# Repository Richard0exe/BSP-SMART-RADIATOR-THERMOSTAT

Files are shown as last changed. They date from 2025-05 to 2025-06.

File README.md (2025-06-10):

# Smart Radiator Thermostat

## Description
This project implements a smart radiator temperature control system. The system allows manual temperature adjustment via a rotary encoder, as well as remote control through a web interface. It uses ESP32 and ESP32-C3 modules, a 28BYJ-48 5V stepper motor for precise temperature regulation, an OLED display (SSD1306), and a DHT11 sensor for measuring ambient temperature. A press button is used to switch between different radiators in the system.

## Features

Manual Temperature Control: Rotate the rotary encoder to adjust the temperature setting.
Web Interface: Use the web server to control radiator temperature remotely via a browser.
Radiator Selection: Press the button to toggle between different radiators.
Real-Time Temperature Monitoring: Displays current temperature readings from the DHT11 sensor on the OLED display.
Precise Valve Control: Uses a stepper motor to adjust radiator valves according to the set temperature.
LIVE thermostat updates when sending new requests, showing status via display.

## Architecture
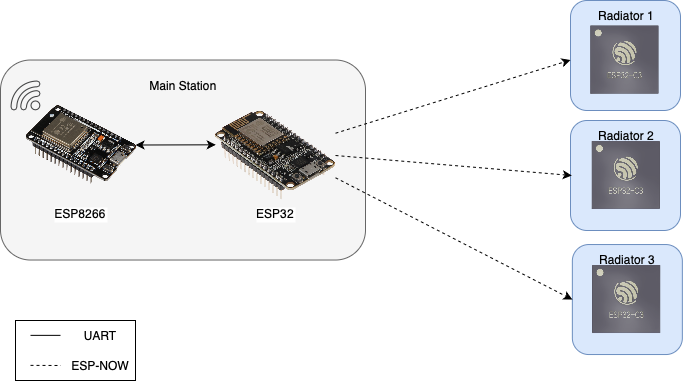
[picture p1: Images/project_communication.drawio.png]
Communication diagram


ESP32 and ESP8266 communicate using UART (Serial bus). ESP8266 holds Web server, ESP32 gets data from Web and sends using ESP-NOW to ESP32C3 radiator nodes.

## Setup

### Hardware
 - Connect the Stepper Motor (28BYJ-48) to the ESP32 using the appropriate motor driver (e.g., ULN2003).
 - OLED Display (SSD1306) connects via I2C to the ESP32.
 - Rotary Encoder connects to two GPIO pins for reading rotational data.
 - DHT11 Sensor connects to a GPIO pin for temperature sensing.
 - Press Button connects to a GPIO pin for switching between radiators.
### Software
 - Install the ESP32 Board support in the Arduino IDE.
 - Install the following libraries:
1. Adafruit_SSD1306 for the OLED display.
2. DHT for the DHT11 sensor.
3. ESPAsyncWebServer for the web server.
4. AsyncTCP
5. LittleFS
 - To Upload the code to your ESP32 use the Arduino IDE.

⚠️ **DON'T FORGET TO!** ⚠️
For uploading WEB files use LittleFS:

ARDUINO IDE -> (CMD + SHIFT + P) -> UPLOAD LittleFS to...

---

## Wiring
### Main module

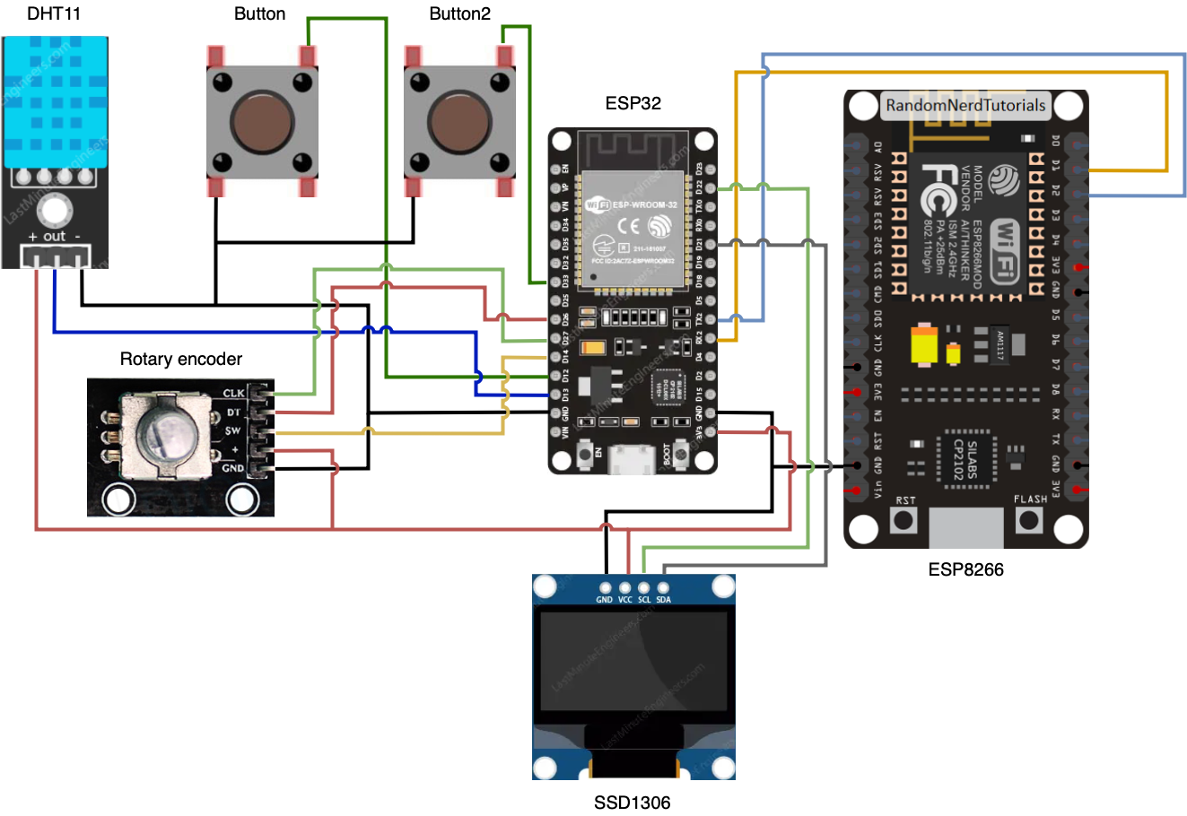
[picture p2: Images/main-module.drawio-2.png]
Main diagram


### Radiator module

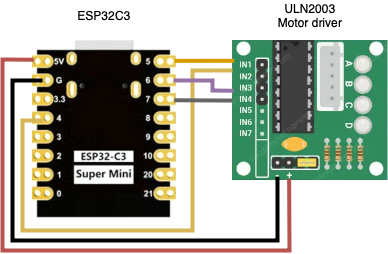
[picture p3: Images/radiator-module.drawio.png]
Radiator diagram


---

#### Web Interface
Once the system is up and running, connect your device to the same network as the ESP8266. Access the web interface by entering the ESP8266's IP address in a web browser. Use the interface to adjust the radiator temperatures remotely.
The IP address to access the server is being printed to serial port.

⚠️ **IMPORTANT!** ⚠️
To find the IP address and other information press the info button

#### Manual Control
Rotate the rotary encoder to adjust the desired temperature for the selected radiator. The OLED display will show the current temperature and the selected radiator. Use the button to switch between different radiators.

# Contributors
- [Ričards Bubišs](https://github.com/Richard0exe?tab=followers)
- [Markuss Birznieks](https://github.com/Markuss-B)

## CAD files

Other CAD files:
3D-Model/valve-trv v20.f3z

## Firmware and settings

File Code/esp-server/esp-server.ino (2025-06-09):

#include <Wire.h>
#include <Adafruit_GFX.h>
#include <Adafruit_SSD1306.h>
#include <DHT.h>
#include <DHT_U.h>
#include <ArduinoJson.h>
#include "Communications.h" 
#include "Messages.h"
#include "RadiatorManager.h"
#include "RadiatorDisplay.h"
#include "WebComs.h"
#include "Button.h"

#define DEBUG FALSE // CHANGE TO TRUE TO ENABLE SERIAL OUTPUTS 

#define SCREEN_WIDTH 128 // OLED display width, in pixels
#define SCREEN_HEIGHT 32 // OLED display height, in pixels

#define DHT_PIN 13 // D13
#define DHT_TYPE DHT11 
#define BUTTON_PIN 12 // D12
#define INFO_BUTTON_PIN 25 // D25

#define RX2 16
#define TX2 17

#define SDA_PIN 21  // Define SDA pin (GPIO 21)
#define SCL_PIN 22  // Define SCL pin (GPIO 22)

#define ENCODER_CLK 27  // D5
#define ENCODER_DT  26  // D6
#define ENCODER_SW  14  // D0 (reuses your button)

// Declaration for an SSD1306 display connected to I2C (SDA, SCL pins)
Adafruit_SSD1306 display(SCREEN_WIDTH, SCREEN_HEIGHT, &Wire, -1);
DHT dht(DHT_PIN, DHT_TYPE);

Communications coms;
RadiatorManager radiatorManager(coms);
RadiatorDisplay radiatorDisplay(display);
WebComs webComs(Serial2, radiatorManager);

Button infoButton(INFO_BUTTON_PIN);

void OnDataRecv(const uint8_t* mac, uint8_t type, const uint8_t* data, int len){
  switch (type) {
    case MSG_TYPE_TEMPERATURE_RESPONSE:
      if (len == sizeof(TemperatureResponse)) {
        TemperatureResponse payload;
        memcpy(&payload, data, sizeof(payload));
        radiatorManager.processTemperatureResponse(mac, payload);
      }
      break;

    default:
      Serial.println("Unknown message type");
      break;
  }
}

void OnDiscoverNewPeer(const Peer& peer) {
  // Add new radiator
  if (strncmp(peer.name, "radiator", MAX_NAME_LEN) == 0) {
    radiatorManager.handleDiscovery(peer);
  } else {
    Serial.printf("Discovered unknown type device: %s (%s)\n", peer.name, Communications::macToString(peer.mac).c_str());
  }
}

void setup() {
  Serial.begin(115200);
  Serial2.begin(9600, SERIAL_8N1, RX2, TX2);

  Wire.begin(SDA_PIN, SCL_PIN);

  pinMode(ENCODER_CLK, INPUT);
  pinMode(ENCODER_DT, INPUT);
  pinMode(ENCODER_SW, INPUT_PULLUP);
  
  pinMode(BUTTON_PIN, INPUT_PULLUP);
  infoButton.begin();
  // Initialize the DHT sensor
  dht.begin();
  
  // Initialize the OLED display
  if (!display.begin(SSD1306_SWITCHCAPVCC, 0x3C)) {
    Serial.println(F("SSD1306 allocation failed"));
    for (;;);
  }
  delay(2000);
  radiatorDisplay.begin();
  
  // Initialize communications
  coms.begin();
  coms.setName("server");

  coms.setReceiveHandler(OnDataRecv);
  coms.setDiscoveryHandler(OnDiscoverNewPeer);

  coms.broadcastDiscovery();
}

//-- Radiator selection satate
int currentRadiatorIndex = -1; // -1 - all, 0-n - all radiators in radiators array
uint8_t commonTemp = DEFAULT_TEMP;
uint8_t rotatorTemp = commonTemp;
uint8_t shownTemp = rotatorTemp;
bool tempChanged = false;

//-- Button and encoder states
int prev_button_state = HIGH;
int button_state;
bool buttonClicked = false;

int lastEncoderButtonState = HIGH;
int lastEncoderState = HIGH;
int encoderClicked = false;

//-- UI States

enum UI_State : uint8_t {
  UI_RADIATORS,
  UI_INFO
};
UI_State state = UI_RADIATORS;
bool changed = false;

void radiatorState(bool redraw = false) {
  if (redraw) {
    radiatorDisplay.redraw();
  }

    // External button pess logic
  button_state = digitalRead(BUTTON_PIN);
  if(button_state == LOW && prev_button_state == HIGH){
    delay(50); // maybe there is a nonblocking way to do this?
    buttonClicked = true;

    currentRadiatorIndex++;
    if(currentRadiatorIndex >= radiatorManager.getNumRadiators()){
      currentRadiatorIndex = -1;
    }

    Serial.print("Selected: ");
    if (currentRadiatorIndex == -1) {
      shownTemp = commonTemp;
      Serial.println("ALL radiators");
    } else {
      shownTemp = radiatorManager.getRadiatorTemperature(currentRadiatorIndex);
      Serial.println(radiatorManager.getRadiatorName(currentRadiatorIndex));
    }

    rotatorTemp = shownTemp; 
  }

  prev_button_state = button_state;

  // Encoder button logic
  int encoderButtonState = digitalRead(ENCODER_SW);
  if(encoderButtonState == LOW && lastEncoderButtonState == HIGH){
    encoderClicked = true;
  } else {
    encoderClicked = false;
  }
  lastEncoderButtonState = encoderButtonState;

  // Rotator logic
  int currentState = digitalRead(ENCODER_CLK);
  if(currentState != lastEncoderState && currentState == LOW){
    int delta = (digitalRead(ENCODER_DT) != currentState) ? 1 : -1;
    rotatorTemp = constrain(rotatorTemp + delta, MIN_TEMP, MAX_TEMP);
    shownTemp = rotatorTemp;
  }
  lastEncoderState = currentState;

  // Encoder button logic
  if(encoderClicked){
    if (currentRadiatorIndex == -1) {
      // Send to all radiators
      commonTemp = rotatorTemp;
      radiatorManager.sendTemperatureToAll(commonTemp);
    } else {
      // Send only to selected radiator
      radiatorManager.sendTemperatureTo(currentRadiatorIndex, rotatorTemp);
    }

    buttonClicked = false;
  }

  // Read DHT sensor values
  float temp = dht.readTemperature();
  float humidity = dht.readHumidity();
  if (isnan(temp) || isnan(humidity)) {
    Serial.println("Failed to read from DHT sensor!");
  } else {
    // Serial.print("Temperature: ");
    // Serial.print(temp);
    // Serial.println("°C");
    // Serial.print("Humidity: ");
    // Serial.print(humidity);
    // Serial.println("%");
  }

  // display logic
  //if 1 from all radiators dont confirm receiving, print CROSS
  bool acked = currentRadiatorIndex == -1 ? radiatorManager.isAllAcked() : radiatorManager.isAcked(currentRadiatorIndex);
  //display choosen radiator
  String name = currentRadiatorIndex == -1 ? "All" : radiatorManager.getRadiatorName(currentRadiatorIndex);
  // If anything has changed then it will update the display
  radiatorDisplay.update(currentRadiatorIndex, name, shownTemp, acked, temp);
}

void infoState(bool redraw) {
  if (!redraw) return; // avoid redrawing

  display.clearDisplay();

  display.setTextSize(1);

  // Display IP
  display.setCursor(0, 0);
  display.print("IP: ");
  display.println(webComs.ip);

  // Display SSID
  display.setCursor(0, 10);
  display.print("SSID: ");
  display.println(webComs.ssid);

  // Display Password
  display.setCursor(0, 20);
  display.print("PWD: ");
  display.println(webComs.password);

  display.display();
}

void loop() {
  // constantly reading Serial2 waiting for some info
  webComs.update();

  infoButton.update();
  if (infoButton.wasPressed()) {
    state = (state == UI_INFO) ? UI_RADIATORS : UI_INFO;
    changed = true;
  } else {
    changed = false;
  }

  switch (state) {
    case UI_RADIATORS:
      radiatorState(changed);
      break;
    case UI_INFO:
      infoState(changed);
      break;
  }
}

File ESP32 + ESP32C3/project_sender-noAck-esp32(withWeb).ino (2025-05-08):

#include <ESPAsyncWebServer.h>
#include <Wire.h>
#include <Adafruit_GFX.h>
#include <Adafruit_SSD1306.h>
#include <DHT.h>
#include <DHT_U.h>
#include <WiFi.h>
#include <esp_now.h>

#include <LittleFS.h>
#include <AsyncTCP.h>

#define DEBUG FALSE // CHANGE TO TRUE TO ENABLE SERIAL OUTPUTS 

#define ESPNOW_CHANNEL 6

#define SCREEN_WIDTH 128 // OLED display width, in pixels
#define SCREEN_HEIGHT 32 // OLED display height, in pixels

#define DHT_PIN 13 // D13
#define DHT_TYPE DHT11 
#define BUTTON_PIN 12 // D12

#define SDA_PIN 21  // Define SDA pin (GPIO 21)
#define SCL_PIN 22  // Define SCL pin (GPIO 22)

#define ENCODER_CLK 27  // D5
#define ENCODER_DT  26  // D6
#define ENCODER_SW  14  // D0 (reuses your button)

#define MIN_TEMP 8
#define MAX_TEMP 28

#define DEFAULT_TEMP 20

const char *ssid = "LMT-F3DD";
const char *password = "QN5QQTY6J16";

uint8_t commonTemp = DEFAULT_TEMP;
bool tempChanged = false;

AsyncWebServer server(80);

String PARAM_MESSAGE = "temperature";

void notFound(AsyncWebServerRequest *request)
{
  request->send(404, "text/plain", "Not found");
}

const unsigned char check_icon [] PROGMEM = {
  0b00000000,
  0b00000001,
  0b00000011,
  0b00000110,
  0b10001100,
  0b11011000,
  0b01110000,
  0b00100000
};

const unsigned char cross_icon [] PROGMEM = {
  0b10000001,
  0b01000010,
  0b00100100,
  0b00011000,
  0b00011000,
  0b00100100,
  0b01000010,
  0b10000001
};

// Declaration for an SSD1306 display connected to I2C (SDA, SCL pins)
Adafruit_SSD1306 display(SCREEN_WIDTH, SCREEN_HEIGHT, &Wire, -1);
DHT dht(DHT_PIN, DHT_TYPE);

int prev_button_state = HIGH;
int button_state;

// Set the MAC address of the receiver (replace with the actual MAC address)
uint8_t receiverMacAddress[] = {0x8C, 0x4F, 0x00, 0x42, 0x02, 0x25}; // Your MAC address

// Data structure to send via ESP-NOW
typedef struct struct_message {
  uint8_t msgType; // Now only type DATA
  uint16_t msgId;
  uint8_t temp; 
} struct_message;

typedef struct { 
  uint8_t mac[6];
  String name;
  uint8_t curr_temp; // hold current temp for each radiator
  bool ackReceived; 
} Radiator;

Radiator radiators[] = {
  { {0x98, 0x88, 0xE0, 0xD9, 0xCB, 0x18}, "Room 1", DEFAULT_TEMP},
  { {0x8C, 0x4F, 0x00, 0x42, 0x02, 0x28}, "Room 2", DEFAULT_TEMP}, // some fake MAC for testing 
};

const int numRadiators = sizeof(radiators) / sizeof(radiators[0]);

// -1 - all, 0-n - all radiators in radiators array
int currentRadiatorIndex = -1;

struct_message myData;

static uint16_t lastMsgId  = 0;

enum MessageType {
  DATA = 0,
  ACK = 1
  };
MessageType messageType;

// Setup ESP-NOW communication
void OnDataSent(const unsigned char *mac_addr, esp_now_send_status_t sendStatus) {
  Serial.print("Send Status to ");

  //Find to which radiator data was sent succesfully
  bool found = false;
  for(int i = 0; i < numRadiators; i++){
    // compare to memory blocks byte by byte , MAC address = 6 bytes 
    if(memcmp(mac_addr, radiators[i].mac, 6) == 0){
      Serial.print((radiators[i].name));
      found = true;

      // Update ackReceived based on send status
      if (sendStatus == ESP_NOW_SEND_SUCCESS) {
        radiators[i].ackReceived = true;  // Success
      } else {
        radiators[i].ackReceived = false; // Failure
      }
      break;
    }
  }
  if(!found) {
    Serial.print("Unknown device");
  }

  Serial.print(": "); 
  if (sendStatus == 0) {
    Serial.println("Success");
  } else {
     Serial.println("Fail");
  }
}

// void OnDataRecv(uint8_t *mac, uint8_t *incomingData, uint8_t len){
//   struct_message incomingMsg;
//   memcpy(&incomingMsg, incomingData, sizeof(incomingMsg));

//   if(incomingMsg.msgType == ACK){
//     for (int i = 0; i < numRadiators; i++) {
//       if (memcmp(mac, radiators[i].mac, 6) == 0 && incomingMsg.msgId == lastMsgId) {
//         radiators[i].ackReceived = true;
//         Serial.print("ACK received from ");
//         Serial.println(radiators[i].name);
//       } 
//     }
//   }
// }

void setup() {
  Serial.begin(115200);
  Wire.begin(SDA_PIN, SCL_PIN);

  pinMode(ENCODER_CLK, INPUT);
  pinMode(ENCODER_DT, INPUT);
  pinMode(ENCODER_SW, INPUT_PULLUP);
  
  pinMode(BUTTON_PIN, INPUT_PULLUP);
  // Initialize the DHT sensor
  dht.begin();
  
  // Initialize the OLED display
  if (!display.begin(SSD1306_SWITCHCAPVCC, 0x3C)) {
    Serial.println(F("SSD1306 allocation failed"));
    for (;;);
  }
  delay(2000);
  display.clearDisplay();
  display.setTextColor(WHITE);
  
  // Initialize Wi-Fi for ESP-NOW
  WiFi.mode(WIFI_STA);
  //WiFi.disconnect(); // Ensure Wi-Fi is off
  //WiFi.channel(ESPNOW_CHANNEL);
  WiFi.begin(ssid, password);
  if (WiFi.waitForConnectResult() != WL_CONNECTED)
  {
    Serial.printf("WiFi Failed!\n");
    return;
  }

  Serial.print("IP Address: ");
  Serial.println(WiFi.localIP());
  
  // Initialize ESP-NOW
  if (esp_now_init() != 0) {
    Serial.println("Error initializing ESP-NOW");
    return;
  }

  esp_now_register_send_cb(OnDataSent);

  //esp_now_register_recv_cb(OnDataRecv);
  
  // Add the receiver as a peer
 for (int i = 0; i < numRadiators; i++) {
  esp_now_peer_info_t peerInfo;
  memset(&peerInfo, 0, sizeof(peerInfo));
  memcpy(peerInfo.peer_addr, radiators[i].mac, 6);
  //peerInfo.channel = ESPNOW_CHANNEL;
  peerInfo.encrypt = false;
  
  esp_now_add_peer(&peerInfo);
}
//Start web and handle
Serial.println("Starting the LittleFS Webserver..");
    // Begin LittleFS
  if (!LittleFS.begin())
  {
    Serial.println("An Error has occurred while mounting LittleFS");
    return;
  }
  // Route for root index.html
  server.on("/", HTTP_GET, [](AsyncWebServerRequest *request)
            { request->send(LittleFS, "/index.html", "text/html"); });

  // Route for root index.css
  server.on("/styles.css", HTTP_GET, [](AsyncWebServerRequest *request)
            { request->send(LittleFS, "/styles.css", "text/css"); });

  // Route for root index.js
  server.on("/script.js", HTTP_GET, [](AsyncWebServerRequest *request)
            { request->send(LittleFS, "/script.js", "text/javascript"); });

  server.on("/edit.svg", HTTP_GET, [](AsyncWebServerRequest *request) {
      request->send(LittleFS, "/edit.svg", "image/svg+xml");  });

  server.on("/delete.svg", HTTP_GET, [](AsyncWebServerRequest *request) {
      request->send(LittleFS, "/delete.svg", "image/svg+xml");  });

  // Respond to toggle event
  server.on("/set", HTTP_GET, [](AsyncWebServerRequest *request)
            {
        String temperature;
        if (request->hasParam(PARAM_MESSAGE)) {
            temperature = request->getParam(PARAM_MESSAGE)->value();
            Serial.print("Received temperature: ");
             Serial.println(temperature);
            if(temperature.length() > 0){
              setTemperature(temperature);
            }
        } else {
            temperature = "No message sent";
        }
        request->send(200, "text/plain", "Received temperature : " + temperature); });

  server.onNotFound(notFound);

  server.begin();
}
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

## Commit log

2025-05-08 Init commit
    Added WebServer files, Added files for 2 ESP8266 configuration, files for ESP32C3 and ESP32 communication. Version for ESP32 have Webserver and rotary encoder control over the temperature. Each folde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
2025-05-10 Added wiring diagrams
    Drawio wiring diagram file and images
2025-05-10 Update README.md
    Add wiring diagrams
2025-05-10 Version update
    New WEB code for ESP8266 and sender code for ESP32, including parsing to json and sending to server node
2025-06-01 Discovery responses to handle cases where one device restarts.
2025-06-01 Renamed file to match folder name so arduino ide can open it.
2025-06-01 Updated server with communications class. Now can discover radiators dynamically; send temperature commands and receive temperate ACKs.
2025-06-02 Updated server with RadiatorManager class to encapsulate the radiator managing logic. Web server interactions not compatible currently.
    [RadiatorManager.cpp, RadiatorManager.h]
2025-06-03 Add GND wire between server-esp and web-esp to avoid noise in serial communication.
2025-06-03 Web communications now working thanks go GND wire.
2025-06-09 Calibrate the movement of the stepper motor
    - Calibrated movement
    - Saving last position to memory, to ensure after reboot it works fine and don't go too far
2025-06-09 Updated esp-server with info screen which shows esp-web ip, ssid, password. Added new button for infor screen with a new Button class. Also added redraw method for RadiatorDisplay
2025-06-09 Updated esp-web: Set individual radiator temperature from web; Synchronise now actually syncs with esp-server.
2025-06-09 Update diagram
    -Added second button wiring
2025-06-09 Fusion 360 Thermostat design
    [valve-trv v20.f3z]
2025-06-10 Update README.md
    Added mistakes not ESP32 but 8266
2026-06-17 Add the final submission
    It does a good job and showcasing the project in Latvian. Maybe better than the current readme
